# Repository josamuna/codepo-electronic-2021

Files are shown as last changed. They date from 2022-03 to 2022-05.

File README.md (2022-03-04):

[![]()](https://monitor-engine.com)

# Monitor Engine - ULB / CODEPO

> Cette partie est le complément logique du module logiciel fait par les étudiants de l'[ISIG-Goma](https://www.isig.ac.cd/) qui se trouve successivement dans ces deux répository ([Backend](https://github.com/josamuna/codepo-backend) et [Frontend](https://github.com/josamuna/codepo-fontend)).

## Table des Matières

1. [Introduction](#Introduction)
2. [Liste des composants électroniques](#Composants)
3. [Schémas électroniques et PCB](#Schémas)
4. [Outils de developpement du code source](#Outils-developpement)
5. [Structure du projet](#Structure)
6. [Utilisation des commandes AT et Thingstream](#Commandes-AT-Thingstream)
7. [Fonctionnement du module électronique](#Fonctionnement)
8. [Récommandations](#Récommandations)
9. [Sponsors](#Sponsors)
10. [Contributeurs](#Contributeurs)
11. [Licence](#Licence)

### Introduction

***

### Liste des composants électroniques

***

### Schémas électroniques et PCB

Le [schéma global](hardware/MSF-Battery-monitor.pdf) est disponible dans le dossier [*hardware*](hardware).

Il peut être divisé en

### Outils de developpement du code source

***

### Structure du projet

***

La structure du projet reprend les dossiers et fichiers suivants détaillés dans cette arborescence:

```
.\
│
├── build\
│   └── default\
│       └── production\
│           ├── adc.o
│           ├── adc.o.d
│           ├── init.o
│           ├── init.o.d
│           ├── main.o
│           ├── main.o.d
│           ├── thingstream.o
│           ├── thingstream.o.d
│           ├── uart1.o
│           └── uart1.o.d
│
├── debug\
│   └── default\
│
│
├── dist\
│   └── default\
│       └── production\
│           ├── codepo-electronic-2021.production.elf
│           ├── codepo-electronic-2021.production.hex
│           ├── codepo-electronic-2021.production.map
│           └── memoryfile.xml
│
├── nbproject\
│   ├── private\
│   │   ├── configurations.xml
│   │   ├── private.xml
│   │   └── SuppressibleMessageMemo.properties
│   │
│   ├── configurations.xml
│   ├── Makefile-default.mk
│   ├── Makefile-genesis.properties
│   ├── Makefile-impl.mk
│   ├── Makefile-local-default.mk
│   ├── Makefile-variables.mk
│   ├── Package-default.bash
│   └── project.xml
│
├── adc.c
├── adc.h
├── init.c
├── init.h
├── LICENSE
├── main.c
├── main.c.dump
├── Makefile
├── README.md
├── thingstream.c
├── thingstream.h
├── uart1.c
├── uart1.h
├── uart1.h.dump
├── uart2.c
└── uart2.h
```

- `..\build\` est le répertoire principal de génération des fichiers objects après compilation. 
- `..\dist\` répertorie de génération des fichier d'utilisation en production.
- `..\nbproject\` répertoire de configuration de l'IDE.
- `..\adc.c` est le fichier permettant d'initialiser la conversion anologue vers digital
- `..\adc.h` est le header du fichier adc.c
- `..\init.c` est le fichier permettant d'initialiser les paramètres du microcontroleur
- `..\init.h` est le header du fichier init.c
- `..\LICENSE` ...............
- `..\main.c` est le fichier principal d'entré du programme. C'est ici que commence l'éxécution du code par le compilateur.
- `..\main.c.dump` ...............
- `..\Makefile` ...............
- `..\README.md` le fichier contenant la documentation du projet.
- `..\thingstream.c` est le fichier contenant les différentes fonctions qui permettent d'envoyer des commandes au module de communication Thingstream Click via l'UART afin de, par exemple, se connecter au reseau, recevoir des messages, en envoyer, etc.
- `..\thingstream.h` est le header du fichier thingstream.c
- `..\uart1.c` est le fichier qui permet la communication UART via 2 pattes (TX et RX) du micro-controleur (communication entre le micro-controleur et le module de communication Thingstream Click)
- `..\uart1.h` est le header du ficier uart1.c
- `..\uart1.dump` ...............
- `..\uart2.c`  est le fichier qui permet la communication UART via 2 autres pattes (TX et RX) du micro-controleur
- `..\uart2.h` est le header du fichier uart2.c
- `..\adc.c` ...............

### Utilisation des commandes AT et Thingstream

***

### Fonctionnement du module électronique

***

### Récommandations

***

### Sponsors

1. En tant que sponsors prépondérant, l'[ULB (Université Libre de Bruxelles)-CODEPO (Cellule de Coopération au Développement de l'Ecole Polytechnique de Bruxelles)](https://polytech.ulb.be/fr/international/cellule-de-cooperation-au-developpement) au sein de la CODEPO assure la mise au point de ce module électronique.

ULB (https://polytech.ulb.be/fr/international/cellule-de-cooperation-au-developpement)

2. Comme financier, l'[ARES(Académie de Recherche et d'Enseignement Supérieur)](https://www.ares-ac.be/fr/) finance bon nombre des activités du projet. ***Il est le bailleur de fond numéro 1***. Néanmoins, l'***ULB*** en tant qu'Institution d'implémentation de la solution, en assure les financements subsidiaires et fournit sa main d'oeuvre (Encadrants, Experts et étudiants).

3. Pour sa par prépondérante dans la collaboration, l'[ISIG (Institut Supérieur d'Informatique et de Gestion de Goma)](https://www.isig.ac.cd/) assure la mise en place de la plateforme logiciel devant communiquer avec le module électronique.
  
ISIG Goma (https://www.isig.ac.cd/)

### Contributeurs

***

 Plusieurs personnes ont apporté leurs pierres dans la mise au point de ce logiciel pour la part de l'ULB et de lISIG, nous rémercions: 
- **Alban Dietrich**: <alban.dietrich@ulb.ac.be>.
- **Antoine Nonclercq** : `+3226503086` , <anoncler@ulb.ac.cd>.
- **Arnaud Depuydt**: <Arnaud.Depuydt@ulb.be>.
- **Cecile Castiaux**. <Cecile.Castiaux@ulb.be>.
- **Josué Isamuna** : `+243972727527` , <josueisamuna@isig.ac.cd>, <https://github.com/josamuna>.
- **Margaux Mannaerts** : <Margaux.Mannaerts@ulb.be>.
- **Maxime Petre** : <vitaltakanic@gmail.com>.
- **Michel Osée** : `+243994814807` , <Michel.Osee@ulb.be>, <https://github.com/miosee>.
- **Nathan Gartner** : <Nathan.Gartner@ulb.be>.
- **Nicolas Wallemacq** : `+32474769804` , <Nicolas.Wallermacq@ulb.be>, <https://github.com/NicolasWa>.
- **Orianne Bastin** : `+3226502838` , <orianne.bastin@ulb.be>.
- **Philippe Mutijima** : <Philippe.Mwansa.Mutijima@ulb.be>.
- **Philippe Questel** : `+32474769804` , <Philippe.Questel@ulb.be>.

### License

***

Ce projet est par ailleurs soumis au droits relatifs à la licence [MIT](https://mit-license.org/).

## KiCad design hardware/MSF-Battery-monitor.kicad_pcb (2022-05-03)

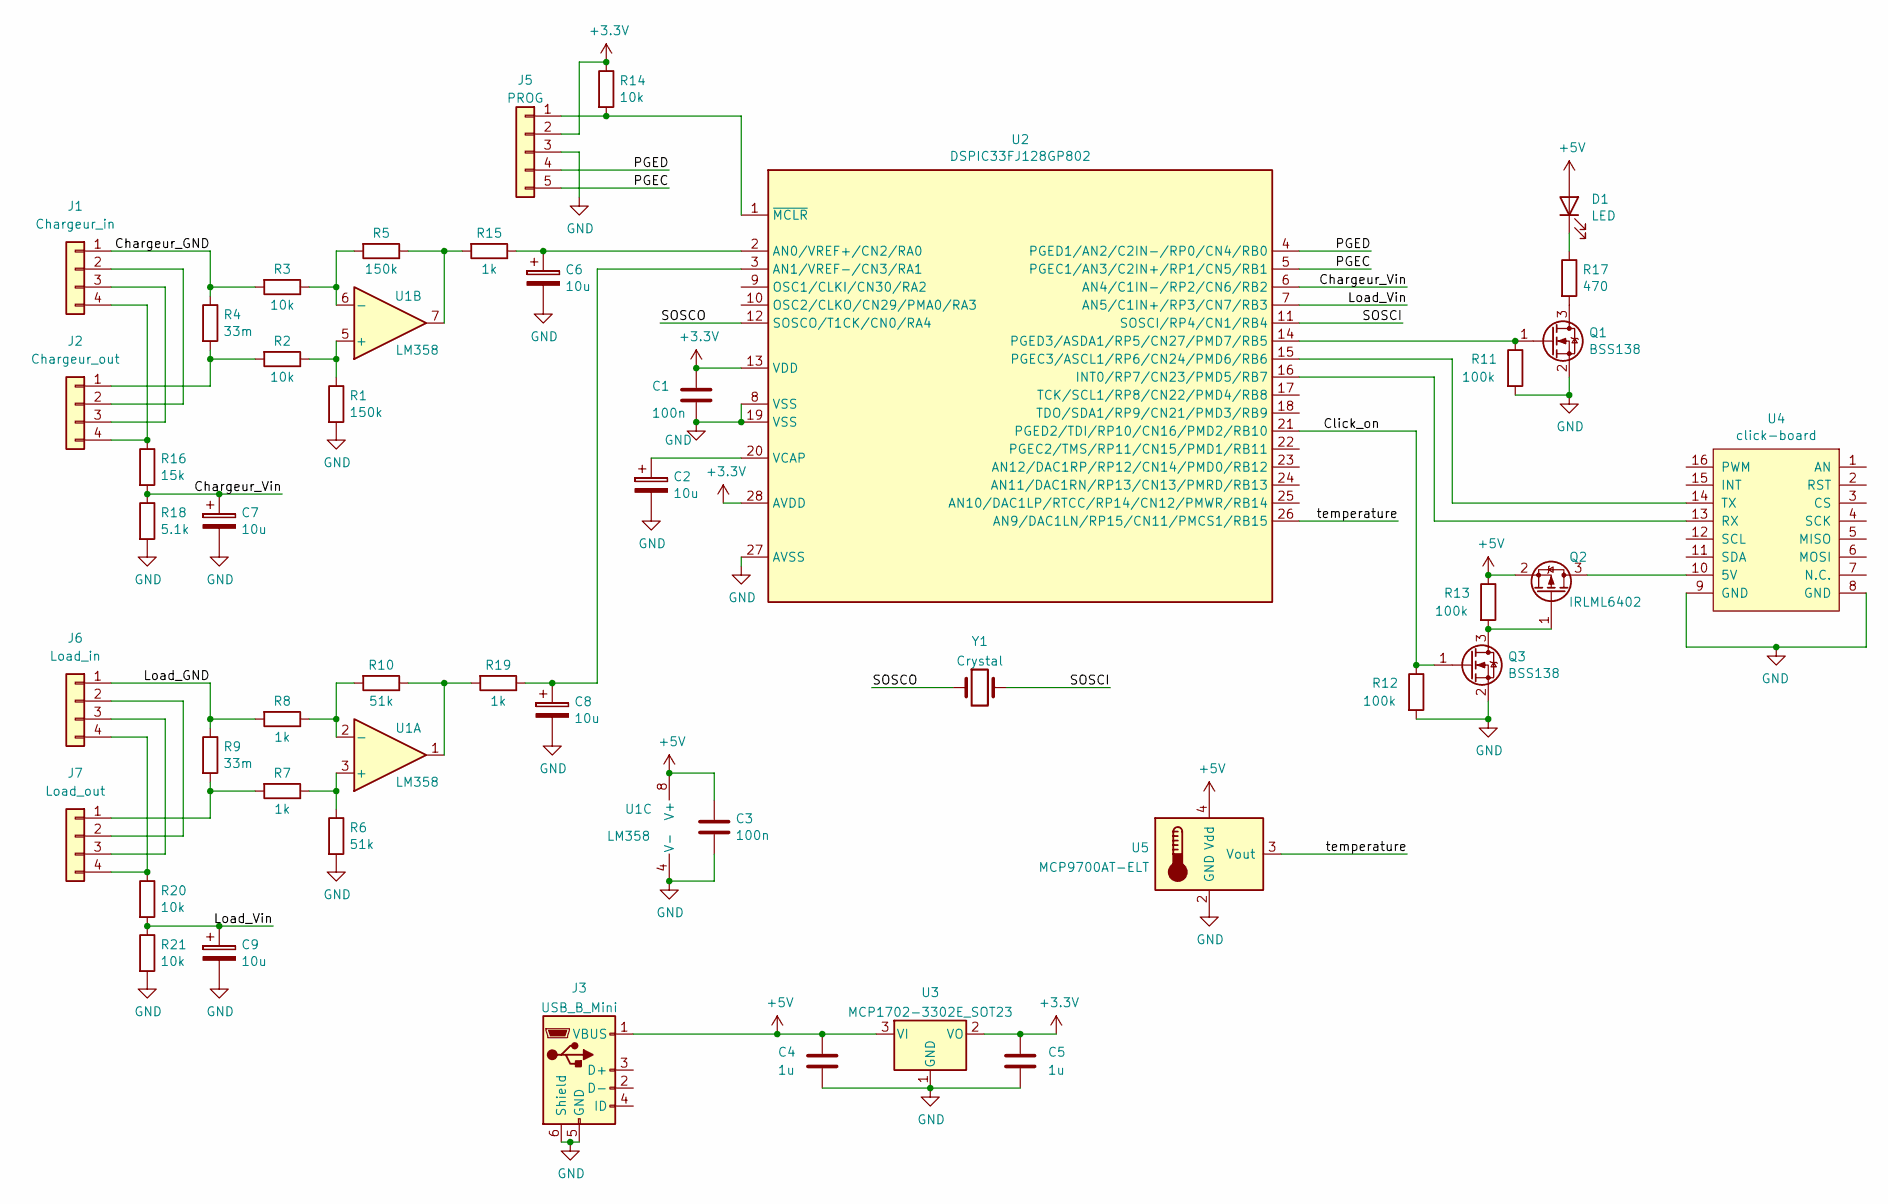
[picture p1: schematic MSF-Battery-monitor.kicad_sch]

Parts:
C1, C3: 100n; C_Disc_D7.0mm_W2.5mm_P5.00mm
C2, C6, C7, C8, C9: 10u; CP_Radial_D6.3mm_P2.50mm
C4, C5: 1u; C_0805_2012Metric_Pad1.18x1.45mm_HandSolder
D1: LED; LED_1206_3216Metric_Pad1.42x1.75mm_HandSolder
J1: Chargeur_in; PinHeader_1x04_P2.54mm_Vertical
J2: Chargeur_out; PinHeader_1x04_P2.54mm_Vertical
J3: USB_B_Mini; USB_Micro-B_Molex-105017-0001
J5: PROG; PinHeader_1x05_P2.54mm_Vertical
J6: Load_in; PinHeader_1x04_P2.54mm_Vertical
J7: Load_out; PinHeader_1x04_P2.54mm_Vertical
Q1, Q3: BSS138; SOT-23
Q2: IRLML6402; SOT-23
R1, R5: 150k; R_Axial_DIN0207_L6.3mm_D2.5mm_P10.16mm_Horizontal
R2, R3, R14, R20, R21: 10k; R_Axial_DIN0207_L6.3mm_D2.5mm_P10.16mm_Horizontal
R4, R9: 33m; R_2512_6332Metric_Pad1.52x3.35mm_HandSolder
R6, R10: 51k; R_Axial_DIN0207_L6.3mm_D2.5mm_P10.16mm_Horizontal
R7, R8, R15, R19: 1k; R_Axial_DIN0207_L6.3mm_D2.5mm_P10.16mm_Horizontal
R11, R12, R13: 100k; R_0805_2012Metric_Pad1.15x1.40mm_HandSolder
R16: 15k; R_Axial_DIN0207_L6.3mm_D2.5mm_P10.16mm_Horizontal
R17: 470; R_0805_2012Metric_Pad1.15x1.40mm_HandSolder
R18: 5.1k; R_Axial_DIN0207_L6.3mm_D2.5mm_P10.16mm_Horizontal
U1: LM358; DIP-8_W7.62mm_LongPads
U2: DSPIC33FJ128GP802; DIP-28_W7.62mm_LongPads
U3: MCP1702-3302E_SOT23; SOT-23
U4: click-board; Click-board
U5: MCP9700AT-ELT; SOT-353_SC-70-5
Y1: Crystal; Crystal_AT310_D3.0mm_L10.0mm_Vertical

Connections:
+3V3: C1.1, C5.1, J5.2, R14.1, U2.13 (VDD), U2.28 (AVDD), U3.2 (VO)
+5V: C3.1, C4.1, D1.2 (A), J3.1 (VBUS), Q2.2 (S), R13.1, U1.8 (V+), U3.3 (VI), U5.4 (Vdd)
/Chargeur_GND: J1.1, R3.2, R4.1
/Chargeur_Vin: C7.1, R16.2, R18.1, U2.6 (AN4/C1IN-/RP2/CN6/RB2)
/Click_on: Q3.1 (G), R12.1, U2.21 (PGED2/TDI/RP10/CN16/PMD2/RB10)
/Load_GND: J6.1, R8.2, R9.1
/Load_Vin: C9.1, R20.2, R21.1, U2.7 (AN5/C1IN+/RP3/CN7/RB3)
/PGEC: J5.5, U2.5 (PGEC1/AN3/C2IN+/RP1/CN5/RB1)
/PGED: J5.4, U2.4 (PGED1/AN2/C2IN-/RP0/CN4/RB0)
/SOSCI: U2.11 (SOSCI/RP4/CN1/RB4), Y1.2
/SOSCO: U2.12 (SOSCO/T1CK/CN0/RA4), Y1.1
/temperature: U2.26 (AN9/DAC1LN/RP15/CN11/PMCS1/RB15), U5.3 (Vout)
GND: C1.2, C2.2, C3.2, C4.2, C5.2, C6.2, C7.2, C8.2, C9.2, J3.5 (GND), J3.6 (Shield), J5.3, Q1.2 (S), Q3.2 (S), R1.2, R6.2, R11.2, R12.2, R18.2, R21.2, U1.4 (V-), U2.8 (VSS), U2.19 (VSS), U2.27 (AVSS), U3.1 (GND), U4.8 (GND), U4.9 (GND), U5.2 (GND)
unnamed: C2.1, U2.20 (VCAP)
unnamed: C6.1, R15.1, U2.2 (AN0/VREF+/CN2/RA0)
unnamed: C8.1, R19.1, U2.3 (AN1/VREF-/CN3/RA1)
unnamed: D1.1 (K), R17.1
unnamed: J1.2, J2.2
unnamed: J1.3, J2.3
unnamed: J1.4, J2.4, R16.1
unnamed: J2.1, R2.2, R4.2
unnamed: J5.1, R14.2, U2.1 (~MCLR)
unnamed: J6.2, J7.2
unnamed: J6.3, J7.3
unnamed: J6.4, J7.4, R20.1
unnamed: J7.1, R7.2, R9.2
unnamed: Q1.1 (G), R11.1, U2.14 (PGED3/ASDA1/RP5/CN27/PMD7/RB5)
unnamed: Q1.3 (D), R17.2
unnamed: Q2.1 (G), Q3.3 (D), R13.2
unnamed: Q2.3 (D), U4.10 (5V)
unnamed: R1.1, R2.1, U1.5 (+)
unnamed: R3.1, R5.2, U1.6 (-)
unnamed: R6.1, R7.1, U1.3 (+)
unnamed: R10.1, R19.2, U1.1
unnamed: R8.1, R10.2, U1.2 (-)
unnamed: R5.1, R15.2, U1.7
unnamed: U2.15 (PGEC3/ASCL1/RP6/CN24/PMD6/RB6), U4.14 (TX)
unnamed: U2.16 (INT0/RP7/CN23/PMD5/RB7), U4.13 (RX)

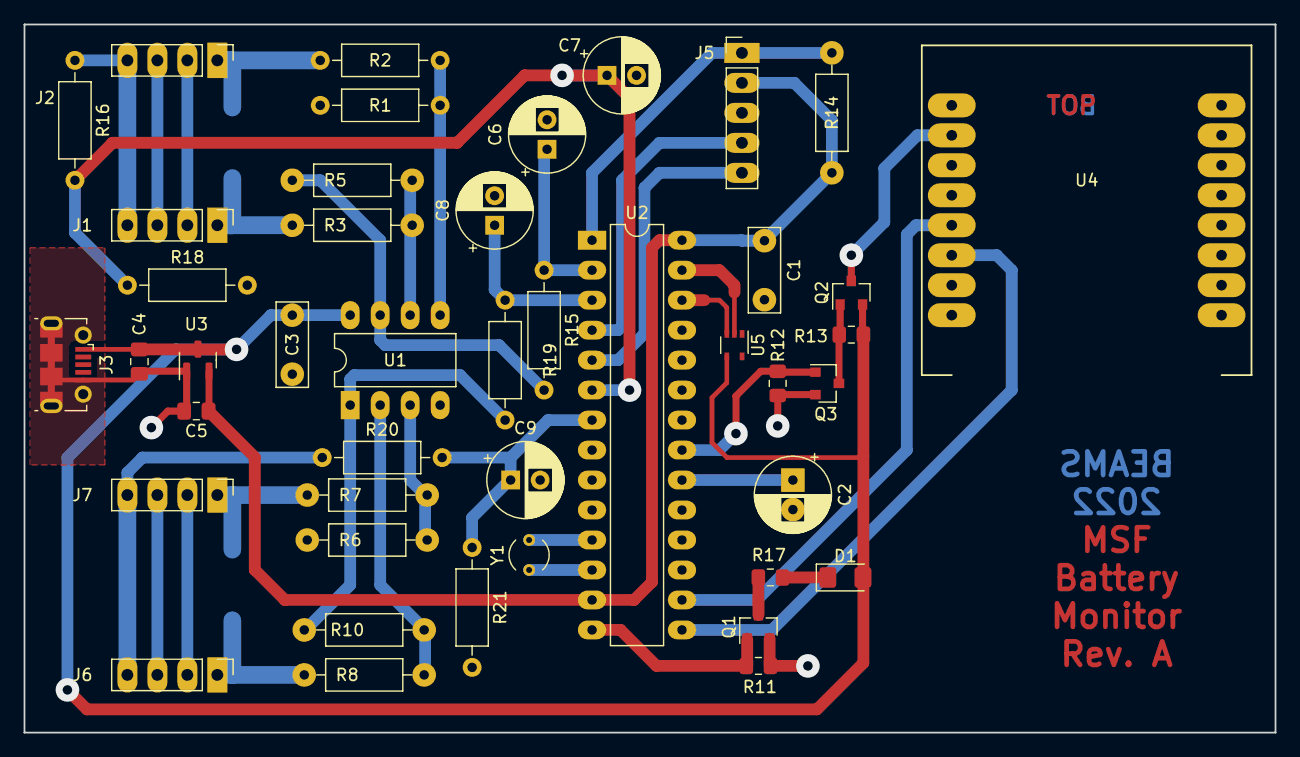
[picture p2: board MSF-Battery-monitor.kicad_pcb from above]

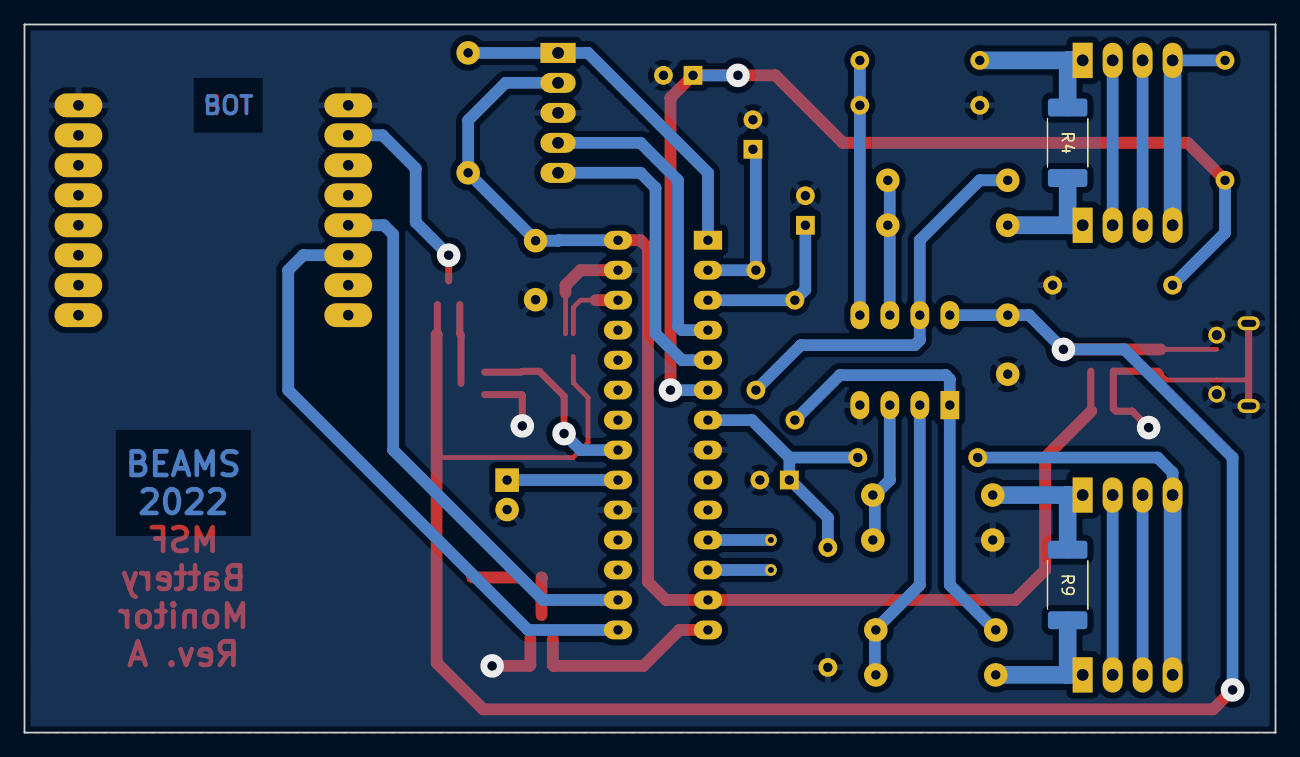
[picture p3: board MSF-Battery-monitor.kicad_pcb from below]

Board: 2 copper layers, 106.0 x 60.0 mm, 46 parts (2 on the bottom side), 38 nets.

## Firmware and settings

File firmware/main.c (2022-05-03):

/* 
 * File:   main.c
 * Author: nicolaswallemacq
 * check this link for fsm template https://www.microchip.com/forums/m520736.aspx
 * Created on May 2, 2021, 3:59 PM
 * This is the main function for the monitoring of the Zendure battery. 
 */

/* Importing libraries specific for the hardware & the microcontroller*/
#include "init.h"
#include "uart1.h"
#include "adc.h" 
#include "thingstream.h" 
#include <xc.h>
#include <libpic30.h>   // FCY definition is in init.h, contains __delay_ms())
#include <time.h>       // contains clock()
// Importing other libraries for message decoding
#include <stdio.h>
#include <stdlib.h>
#include <string.h>



#define COMM_PERIOD_H       4                       // Période d'envoi des messages, en heures
#define TIMER1_PERIOD_S     10                      // Durée d'un "sleep", en secondes
#define GPS_MAX_TRY         (120/TIMER1_PERIOD_S)   // max duration fot trying to get GPS coordinates
uint16_t commSleepThreshold = (COMM_PERIOD_H * 3600ul) / TIMER1_PERIOD_S;    // number of timer1 period between messages

// MQTT topics
char publishTopic[] = "DtW\0";
char caseId[9] = "FICT8C79\0";
/* Send the µC in sleep mode, then after wake-up, update the measurements*/
void sleepFunction(void);

void write_string(char *dest, char text[]);
int getSubString(char *source, char *target, int from, int to);
void extract_relevant_data(char* relevant_data);
void extract_data_msg(char message_received[]);
void extract_lat_long(char *lat, char *longi, char echo_gnss[]);

/* Defining the different states of the finite state machine */
typedef enum {
    IDLE,
    MEASURE,
    ESTABLISHCONNECTION,
    LISTENING,
    GPS_INIT,
    GPS_READ,
    SENDING,
    DESTROY_CONNECTION,
    ERROR
} fsmState_t;


float isrChargeEnergy = 0;
float isrLoadEnergy = 0;
uint16_t isrCommSleepCount = 0;
void __attribute__((interrupt, auto_psv)) _T1Interrupt( void ) {
    float current;
    float voltage;
    
    LED_ON();
    // Mesure du courant
    AD1CHS0bits.CH0SA = ICHARGE_CHANNEL; 
    AD1CON1bits.SAMP = 0;
    while (!AD1CON1bits.DONE);
    AD1CON1bits.DONE = 0;
    current = ICHARGE_GAIN * ADC1BUF0;
    // Mesure de la tension
    AD1CHS0bits.CH0SA = VCHARGE_CHANNEL;
    while (!AD1CON1bits.DONE);
    AD1CON1bits.DONE = 0;
    voltage = VCHARGE_GAIN * ADC1BUF0;
    isrChargeEnergy += voltage * current * TIMER1_PERIOD_S;

    // Mesure du courant
    AD1CHS0bits.CH0SA = ILOAD_CHANNEL; 
    AD1CON1bits.SAMP = 0;
    while (!AD1CON1bits.DONE);
    AD1CON1bits.DONE = 0;
    current = ILOAD_GAIN * ADC1BUF0;
    // Mesure de la tension
    AD1CHS0bits.CH0SA = VLOAD_CHANNEL;
    while (!AD1CON1bits.DONE);
    AD1CON1bits.DONE = 0;
    voltage = VLOAD_GAIN * ADC1BUF0;
    isrLoadEnergy += voltage * current * TIMER1_PERIOD_S;
    
    isrCommSleepCount++;
}


/* Main function: implemented as a finite state machine*/
int main(void) {
    fsmState_t fsmState;
    tsError_t tsError;
    float chargeEnergy, loadEnergy;     // Energy given by the charger/fed to the load since last message
    gpsCoord_t gpsCoord;    // GPS coordinates, given by the click-board
    char errStr[] = "201";      // Error code that will replace ths GPS coordinates if GPS initialisation of click-board fails
    workMode_t workMode = BAT;  // Current work mode
    float temperature = 20.22;  // temperature in the case
    uint16_t gpsCount;



    /* Serial & Pins Setup */
    pinInit();
    LED_ON();
    adcInit(ADC_MANUAL_SAMPLING); // Configuration de L'ADC pour un declenchement par adcStart())
    uart1Config(115200, FCY, UART_8N1_NO_HANDSHAKE);

    /* Starting the finite state machine by entering the AWAKE state */
    fsmState = IDLE;

    while (1) {
        switch (fsmState) {
            /** Idle state: 
             * Go to Idle mode to minimize power consumption.
             * Timer1 interrupt gets us out of IDLE (and turns the LED on to
             * refresh the power pack.
             * After 500ms, turn the LED off, then
             * check if it's time to send message */
            case IDLE:
                Idle(); 
                __delay_ms(500);
                LED_OFF();
                if (isrCommSleepCount > commSleepThreshold) {
                    isrCommSleepCount = 0;  // no need for a critical section (atomic operation)
                    fsmState = ESTABLISHCONNECTION;
                }
                break;

            case ESTABLISHCONNECTION:
                THINGSTREAM_POWER_ON(); // SWITCHING ON THE COMMUNICATION MODULE
                __delay_ms(100);
                THINGSTREAM_UART_ENABLE(); // SWITCHING ON THE UART CHANNEL

                tsError = tsCreate();
                if (tsError == NO_ERROR) {
                    tsError = tsConnect();
                }
                if (tsError == NO_ERROR) {
                    fsmState = LISTENING;
                } else {
                    fsmState = ERROR;
                }
                break;

            case LISTENING:
                /* Listening for messages sent by the server to this device. A message can only be received 
                  once subscribed to the topic the message was posted on */
/*                tsError = tsSubscribe(caseId0);
                if (tsError == NO_ERROR) {
                    tsError = tsReceiveMsg(receivedMsg, MSG_RECEIVED_LENGTH);
                    if (tsError == NO_ERROR) {
                        //extract_data_msg(receivedMsg); // extraction of the relevant data
                    }
                }
                tsError = tsUnsubscribe();
*/
                if (tsError != NO_ERROR) {
                    fsmState = ERROR;
                }
                else if (workMode == BAT) {
                    fsmState = SENDING;
                } else if (workMode == BAT_GPS) {
                    fsmState = GPS_INIT;
                } else { //for mode ECONOMY
                    fsmState = DESTROY_CONNECTION;
                }
                break;

            case SENDING:
                _T1IE = 0;
                chargeEnergy = isrChargeEnergy;
                isrChargeEnergy = 0;
                loadEnergy = isrLoadEnergy;
                isrLoadEnergy = 0;
                _T1IE = 1;
                tsError = tsPublish(publishTopic, caseId, chargeEnergy, loadEnergy, gpsCoord, workMode, TIMER1_PERIOD_S, COMM_PERIOD_H, temperature);

                if (tsError == NO_ERROR) {
                    fsmState = DESTROY_CONNECTION;
                } else {
                    fsmState = ERROR;
                }
                break;


            case ERROR:
            case DESTROY_CONNECTION:
                /* DESTROYCONNECTION state: destruction of the connection we have with the Thingstream Server */
                //tsError = tsDisconnect();
                tsError = tsDestroy();
                THINGSTREAM_UART_DISABLE(); // SWITCHING OF THE UART CHANNEL
                THINGSTREAM_POWER_DOWN();   // SWITCHING OFF THE COMMUNICATION MODULE
                fsmState = IDLE;
                break;

            case GPS_INIT:
                tsError = tsGNSSpowerOn();
                if (tsError == NO_ERROR) {
                    gpsCount = 0;
                    fsmState = GPS_READ;
                } else {
                    strcpy(gpsCoord.longitude, errStr);
                    strcpy(gpsCoord.latitude, errStr);
                    fsmState = SENDING;
                }
                break;
                
            case GPS_READ:
                Idle();
                if (gpsCount++ < GPS_MAX_TRY) {
                    if (tsGNSSCmd(&gpsCoord) == NO_ERROR) {
                        // tsGNSSpowerOff();    // creates an "unespected error" from the click board
                        fsmState = SENDING;
                    }
                } else {
                    fsmState = SENDING;
                }
                break;
        }
    }
    return (0);
}


/* Used to write a string into a char array*/
void write_string(char *dest, char text[]) {
    int len = strlen(text);
    int i = 0;
    for (i = 0; i < len; i++) {
        dest[i] = text[i];
    }
    dest[len] = '\0';
}

/*
// Used to extract a substring located between the indexes 'from' and 'to' from 'source' and store it into 'target'. 
int getSubString(char *source, char *target, int from, int to) {
    int length = 0;
    int i = 0, j = 0;
    length = strlen(source);
    if (from < 0 || from > length) {
        printf("Invalid \'from\' index\n");
        return 1;
    }
    if (to > length) {
        printf("Invalid \'to\' index\n");
        return 1;
    }
    for (i = from; i <= to; i++) {
        target[j] = source[i];
        j++;
    }
    target[j] = '\0';
    return 0;
}
*/
/*
// Used to extract the relevant data (mode, interval_bat_s, interval_sending_h) from the message received from the web 
void extract_relevant_data(char* relevant_data) {
    //int table[3];
    int table[5];
    int mode_prev = workMode;
    //int interval_bat_s_prev = interval_bat_s;
    //int interval_sending_h_prev = interval_sending_h;
    int temp = 1;
    int a = 0;
    int len = strlen(relevant_data);
    int i = 0;
    
    for (i = 0; i < len; i++) {
        if (relevant_data[i] == ',') {
            table[a] = i;
            a++;
        }
    }

    temp = atoi(&relevant_data[0]);
    if (temp >= mode_lower_bound && temp <= mode_upper_bound) {
        workMode = temp;
    } else {
        workMode = mode_prev;
    }

    temp = atoi(&relevant_data[table[0] + 1]);
    if (temp >= interval_bat_s_lower_bound && temp <= interval_bat_s_upper_bound) {
//        interval_bat_s = temp;
    } else {
//        interval_bat_s = interval_bat_s_prev;
    }

    temp = atoi(&relevant_data[table[1] + 1]);
    if (temp >= interval_sending_h_lower_bound && temp <= interval_sending_h_upper_bound) {
//        interval_sending_h = temp;
    } else {
//        interval_sending_h = interval_sending_h_prev;
    }

    char tempo[10];
    const char nanStr[4] = "nan";
    if (getSubString(relevant_data, tempo, table[2] + 1, table[3] - 1) == 0) {
    } else {
    } //error
    if (strcmp(tempo, nanStr) == 0) {
        total_capacity = atoi((const char *) tempo);
    }
    if (getSubString(relevant_data, tempo, table[3] + 1, strlen(relevant_data)) == 0) {
    } else {
    } //error

    if (strcmp(tempo, nanStr) == 0) {
        energyIn = atoi((const char *) tempo);
        gauge = energyIn*total_capacity;
    }
}

// Used to sp
void extract_data_msg(char message_received[]) {
    #define MSG_RECEIVED_LENGTH 50
    char receivedMsg[MSG_RECEIVED_LENGTH];
    char ch = 34; //character ' " '
    int i = 0;
    int ind = 0;
    int indexes_quotation_mark[4];

    while (message_received[i] != '\0') {
        if (message_received[i] == ch) {
            indexes_quotation_mark[ind] = i;
            ind++;
        }
        i++;
    }
    char topic[10];
    char relevant_info[15];

    if (getSubString(receivedMsg, topic, indexes_quotation_mark[0] + 1, indexes_quotation_mark[1] - 1) == 0) {
    } else {
    } //error
    if (getSubString(receivedMsg, relevant_info, indexes_quotation_mark[2] + 1, indexes_quotation_mark[3] - 1) == 0) {
    } else {
    } //error

    extract_relevant_data(relevant_info);
}
*/

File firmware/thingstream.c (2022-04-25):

#include <xc.h>
#include "init.h"
#include "thingstream.h"
#include "uart1.h"

#include <stdio.h>
#include <string.h>
#include <time.h>
#include <ctype.h>



#define CREATE_CMD_LENGTH  13
char createCmd[CREATE_CMD_LENGTH] = "AT+IOTCREATE\n";
#define CREATE_RESPONSE_LENGTH 21
char createSuccessResponse[CREATE_RESPONSE_LENGTH] = "+IOTCREATE: SUCCESS\r\n";

tsError_t tsCreate(void) {
    char response[CREATE_RESPONSE_LENGTH];
    tsError_t error;
    
    error = tsSendInstruction(createCmd, CREATE_CMD_LENGTH, response, CREATE_RESPONSE_LENGTH);
    
    if (error == NO_ERROR) {
        error = tsCheckResponse(response, createSuccessResponse, CREATE_RESPONSE_LENGTH);
    }
    
    return (error);
}



#define DESTROY_CMD_LENGTH  14
char destroyCmd[DESTROY_CMD_LENGTH] = "AT+IOTDESTROY\n";
#define DESTROY_RESPONSE_LENGTH 22
char destroySuccessResponse[DESTROY_RESPONSE_LENGTH] = "+IOTDESTROY: SUCCESS\r\n";

tsError_t tsDestroy(void) {
    char response[DESTROY_RESPONSE_LENGTH];
    tsError_t error;
    
    error = tsSendInstruction(destroyCmd, DESTROY_CMD_LENGTH, response, DESTROY_RESPONSE_LENGTH);
    
    if (error == NO_ERROR) {
        error = tsCheckResponse(response, destroySuccessResponse, DESTROY_RESPONSE_LENGTH);
    }
    
    return (error);
}



#define CONNECT_CMD_LENGTH  19
char connectCmd[CONNECT_CMD_LENGTH] = "AT+IOTCONNECT=true\n";
#define CONNECT_RESPONSE_LENGTH 22
char connectSuccessResponse[CONNECT_RESPONSE_LENGTH] = "+IOTCONNECT: SUCCESS\r\n";

tsError_t tsConnect(void) {
    char response[CONNECT_RESPONSE_LENGTH];
    tsError_t error;
    
    error = tsSendInstruction(connectCmd, CONNECT_CMD_LENGTH, response, CONNECT_RESPONSE_LENGTH);
    
    if (error == NO_ERROR) {
        error = tsCheckResponse(response, connectSuccessResponse, CONNECT_RESPONSE_LENGTH);
    }
    
    return (error);
}



#define DISCONNECT_CMD_LENGTH  17
char disconnectCmd[DISCONNECT_CMD_LENGTH] = "AT+IOTDISCONNECT\n";
#define DISCONNECT_RESPONSE_LENGTH 25
char disconnectSuccessResponse[DISCONNECT_RESPONSE_LENGTH] = "+IOTDISCONNECT: SUCCESS\r\n";

tsError_t tsDisconnect(void) {
    char response[DISCONNECT_RESPONSE_LENGTH];
    tsError_t error;
    
    error = tsSendInstruction(disconnectCmd, DISCONNECT_CMD_LENGTH, response, DISCONNECT_RESPONSE_LENGTH);
    
    if (error == NO_ERROR) {
        error = tsCheckResponse(response, disconnectSuccessResponse, DISCONNECT_RESPONSE_LENGTH);
    }
    
    return (error);
}



#define SUBSCRIBE_CMD_LENGTH 29
#define SUBSCRIBE_RESPONSE_LENGTH 24
char subscribeSuccessResponse[SUBSCRIBE_RESPONSE_LENGTH] = "+IOTSUBSCRIBE: SUCCESS\r\n";

tsError_t tsSubscribe(char *topic) {
    char response[SUBSCRIBE_RESPONSE_LENGTH];
    tsError_t error;
    char subscribeCmd[SUBSCRIBE_CMD_LENGTH];
    
    sprintf(subscribeCmd, "AT+IOTSUBSCRIBE=\"%s\",2\n", topic) ;
    error = tsSendInstruction(subscribeCmd, SUBSCRIBE_CMD_LENGTH, response, SUBSCRIBE_RESPONSE_LENGTH);
    
    if (error == NO_ERROR) {
        error = tsCheckResponse(response, subscribeSuccessResponse, SUBSCRIBE_RESPONSE_LENGTH);
    }
    
    return (error);
}



#define UNSUBSCRIBE_CMD_LENGTH 24
char unsubscribeCmd[UNSUBSCRIBE_CMD_LENGTH] = "AT+IOTUNSUBSCRIBE=\"WtD\"\n";
#define UNSUBSCRIBE_RESPONSE_LENGTH 26
char unsubscribeSuccessResponse[UNSUBSCRIBE_RESPONSE_LENGTH] = "+IOTUNSUBSCRIBE: SUCCESS\r\n";

tsError_t tsUnsubscribe(void) {
    char response[UNSUBSCRIBE_RESPONSE_LENGTH];
    tsError_t error;
    
    error = tsSendInstruction(unsubscribeCmd, UNSUBSCRIBE_CMD_LENGTH, response, UNSUBSCRIBE_RESPONSE_LENGTH);
    
    if (error == NO_ERROR) {
        error = tsCheckResponse(response, unsubscribeSuccessResponse, UNSUBSCRIBE_RESPONSE_LENGTH);
    }
    
    return (error);
}



#define GNSSpowerON_CMD_LENGTH 16
char GNSSpowerOnCmd[GNSSpowerON_CMD_LENGTH] = "AT+IOTCGNSPWR=1\n";
#define GNSSpowerON_RESPONSE_LENGTH 22
char GNSSpowerOnSuccessResponse[GNSSpowerON_RESPONSE_LENGTH] = "+IOTCGNSPWR: SUCCESS\r\n";

tsError_t tsGNSSpowerOn(void) {
    char response[GNSSpowerON_RESPONSE_LENGTH];
    tsError_t error;
    
    error = tsSendInstruction(GNSSpowerOnCmd, GNSSpowerON_CMD_LENGTH, response, GNSSpowerON_RESPONSE_LENGTH);
    
    if (error == NO_ERROR) {
        error = tsCheckResponse(response, GNSSpowerOnSuccessResponse, GNSSpowerON_RESPONSE_LENGTH);
    }
    
    return (error);
}

#define GNSS_CMD_LENGTH 14
char GNSSCmd[GNSS_CMD_LENGTH] = "AT+IOTCGNSINF\n";
#define GNSS_CMD_RESPONSE_LENGTH 150
//char GNSSCmdSuccessResponse[GNSS_CMD_RESPONSE_LENGTH] = "+IOTCGNSINF: 1,1";

tsError_t tsGNSSCmd(gpsCoord_t* gpsCoord) {
    char response[GNSS_CMD_RESPONSE_LENGTH];
    tsError_t error;
    
    error = tsSendInstruction(GNSSCmd, GNSS_CMD_LENGTH, response, GNSS_CMD_RESPONSE_LENGTH);
    if (error ==  NO_ERROR) {
        error = gpsGetCoord(gpsCoord, response);
    }
   
    return (error);
}



#define GNSSpowerOFF_CMD_LENGTH 16
char GNSSpowerOffCmd[GNSSpowerOFF_CMD_LENGTH] = "AT+IOTCGNSPWR=0\n";
#define GNSSpowerOFF_RESPONSE_LENGTH 22
char GNSSpowerOffSuccessResponse[GNSSpowerOFF_RESPONSE_LENGTH] = "+IOTCGNSPWR: SUCCESS\r\n";

tsError_t tsGNSSpowerOff(void) {
    char response[GNSSpowerOFF_RESPONSE_LENGTH];
    tsError_t error;
    
    error = tsSendInstruction(GNSSpowerOffCmd, GNSSpowerOFF_CMD_LENGTH, response, GNSSpowerOFF_RESPONSE_LENGTH);
    
    if (error == NO_ERROR) {
        error = tsCheckResponse(response, GNSSpowerOffSuccessResponse, GNSSpowerOFF_RESPONSE_LENGTH);
    }
    
    return (error);
}



#define PUBLISH_RESPONSE_LENGTH 22
char publishSuccessResponse[PUBLISH_RESPONSE_LENGTH] = "+IOTPUBLISH: SUCCESS\r\n";

tsError_t tsPublish(char *topic, char *caseId, double energyIn, double energyOut, gpsCoord_t coord, workMode_t mode, int16_t intervalBatSec, int16_t intervalSendingHour, double temperature) {
    char response[UNSUBSCRIBE_RESPONSE_LENGTH];
    tsError_t error;
    int16_t length;
    char publishCmd[250];

    if (mode == BAT) {
        length = sprintf(publishCmd, "AT+IOTPUBLISH=\"%s\",1,\"{&caseid&: %s, &IN&: %.2f, &OUT&: %.2f, &latitude&: hidden, &longitude&: hidden, &mode&: %d, &interval_bat_s&: %d, &interval_sending_h&: %d, &temp&: %.2f}\",true\n",
                                 topic, caseId, energyIn, energyOut, mode, intervalBatSec, intervalSendingHour, temperature);
    } else if (mode == BAT_GPS) {
        length = sprintf(publishCmd, "AT+IOTPUBLISH=\"%s\",1,\"{&caseid&: %s, &IN&: %.2f, &OUT&: %.2f, &latitude&: %s, &longitude&: %s, &mode&: %d, &interval_bat_s&: %d, &interval_sending_h&: %d, &temp&: %.2f}\",true\n",
                                 topic, caseId, energyIn, energyOut, coord.latitude, coord.longitude, mode, intervalBatSec, intervalSendingHour, temperature);
    }
    error = tsSendInstruction(publishCmd, length, response, PUBLISH_RESPONSE_LENGTH);

    if (error == NO_ERROR) {
        error = tsCheckResponse(response, publishSuccessResponse, PUBLISH_RESPONSE_LENGTH);
    }
    
    return (error);
}
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

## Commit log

2022-02-07 Update README.md
    adc.c est mentionné deux fois , est-ce normal? J'ai complété les pointillés des fonctions que nous avions faites. Les fichiers .dumps ne sont pas importants
2022-03-04 Réorganisation de l'arborescence + début de documentation
    [MSF-Battery-monitor.kicad_pcb, MSF-Battery-monitor.kicad_sch]
2022-03-14 Bug fix: lecture des messages du click
    En cas de message d'erreur, s'il est plus long que le message de succès, on ne lisait pas tous les caractères du message, ce qui se répercutait sur le message suivant.
    [thingstream.c]
2022-04-01 adaptation au nouveau PCB
    ajout d'une simulation de multi-modules
    [MSF-Battery-monitor.kicad_pcb]
2022-04-25 seconde tentative
    [MSF-Battery-monitor.kicad_pcb, MSF-Battery-monitor.kicad_sch]
2022-05-03 passage au timer1 et mise à jour du PCB
    [MSF-Battery-monitor.kicad_pcb, MSF-Battery-monitor.kicad_sch]
